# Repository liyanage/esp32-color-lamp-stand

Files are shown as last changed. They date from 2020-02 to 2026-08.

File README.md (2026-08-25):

# Color Lamp Stand — User Guide

This illuminated stand connects to Wi-Fi and uses its 32 LEDs to show whether
a stock selected in the firmware is up or down: green for up, red for down, and
white when no current value is available. The stock cannot currently be changed
through the Wi-Fi setup page.

This is the default behavior, but you could modify the software to do something
completely different or custom with the LEDs and the Internet connection.

## Hardware

You need:

- A USB-C power source that can provide at least 1.5 A. A USB-C wall charger is
  ideal; a computer USB-C port also works.
- A USB-C cable for power.

Feed the cable through the base and tie a loose knot inside for strain relief,
as shown below. Do not pull the knot tight enough to damage the cable.

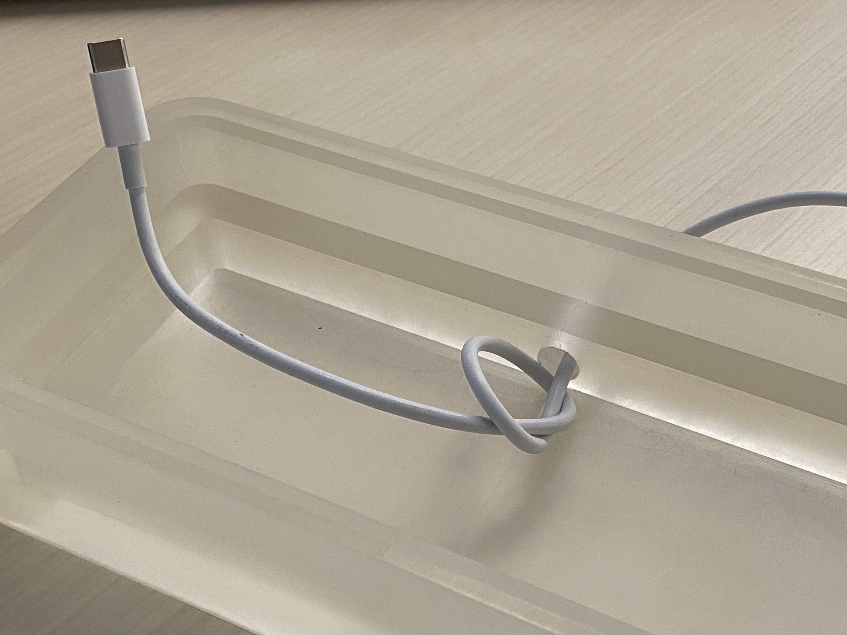
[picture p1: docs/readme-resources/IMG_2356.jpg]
Knot in USB-C cable for strain relief


Connect the USB-C plug to the socket on the circuit board.

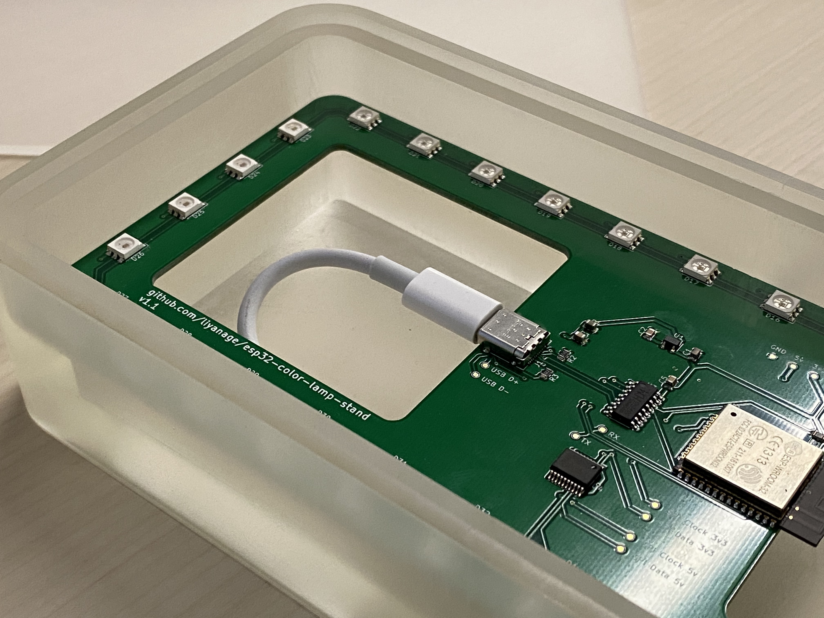
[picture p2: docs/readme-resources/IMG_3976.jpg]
USB-C cable plugged into the circuit board


Fit the translucent cover, then place the object you want to illuminate on top.

## Wi-Fi configuration

On first use, the stand pulses amber and creates a temporary Wi-Fi network named
`ColorLamp-Setup-XXXX`, where the last four characters are unique to your stand.

1. On a phone, tablet, or computer, open Wi-Fi settings and join that network.
   It intentionally has no password and may be described by your device as
   having no internet.
2. The setup page should open automatically. If it does not, open
   [http://192.168.4.1](http://192.168.4.1) in a web browser.
3. Select your home Wi-Fi network, enter its password, and choose **Connect**.
4. The stand pulses blue while it tests the connection. Green means setup
   succeeded and the stand will restart. Red means it could not connect; check
   the network and password, then try again.

Your Wi-Fi password is stored only on the stand.

### Changing the Wi-Fi network

With the stand fully started, hold the **BOOT** button on the circuit board for
five seconds. The LEDs turn red, the saved Wi-Fi details are erased, and the
stand restarts in setup mode.

Do not hold **BOOT** while plugging in power or pressing **RESET**. That button
also activates the ESP32's programming mode during startup.

## What the lights during startup mean

### Power check

Immediately after power-on, a short sweep reports how much current the connected
USB-C source advertises. The stand uses this information to limit LED brightness.
The sweep fills, pauses for about a second, and fades away.

USB-C power capability light patterns

- **8 amber LEDs — USB default:** The stand uses a conservative, low-brightness
  limit. For better illumination, try a USB-C charger rated for at least 1.5 A.
- **16 cyan LEDs — 1.5 A:** Normal operation with good available brightness.
- **32 green LEDs — 3 A:** The source advertises the highest supported current.
- **Two red flashes, then 8 amber LEDs:** The stand could not read the source
  capability and safely selected the conservative limit.

This is the capability advertised by the power source, not a measurement of how
much current the stand is presently consuming.

### Wi-Fi and setup

After the power check, the entire perimeter shows the Wi-Fi state.

Wi-Fi setup and connection light patterns

- **Solid blue:** Connecting to the saved Wi-Fi network.
- **Pulsing amber:** Waiting for you to join `ColorLamp-Setup-XXXX` and complete
  setup.
- **Pulsing blue:** Testing the Wi-Fi name and password you entered.
- **Solid green:** Connected successfully. After initial setup, the stand soon
  restarts automatically.
- **Solid red:** The attempted Wi-Fi connection failed.
- **Bright red after holding BOOT:** Saved Wi-Fi details are being erased.

## Troubleshooting

- **The setup page did not open:** Stay connected to `ColorLamp-Setup-XXXX` and
  open [http://192.168.4.1](http://192.168.4.1) manually. Temporarily disabling
  cellular data or a VPN can help if the phone leaves the setup network.
- **The stand keeps returning to amber setup mode:** Re-enter the Wi-Fi password
  and make sure the selected network is available where the stand will be used.
- **The light is unusually dim:** Check the power-on sweep. Eight amber LEDs mean
  the power source advertised only the default USB current; try another USB-C
  charger and cable.
- **You need to start over:** Let the stand finish booting, then hold **BOOT** for
  five seconds.

## Want to modify it?

The hardware and especially firmware are open for experimentation. See the
[modification guide](MODIFYING.md) for the source layout, fixed GPIO assignments,
KiCad design overview, and build workflow.

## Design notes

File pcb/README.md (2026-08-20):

# PCB development

The KiCad project files and the project-local symbol library are the hardware
sources. Edit the schematic in KiCad, update the PCB with `F8`, and route or
refill zones in the PCB Editor.

KiCad 10 and Python 3 are required. On macOS the exporter finds KiCad in
`/Applications/KiCad`; elsewhere, put `kicad-cli` on `PATH` or set
`KICAD_CLI`.

From this directory:

```sh
make check
make manufacturing
```

`make check` runs schematic ERC and PCB DRC, including schematic/PCB parity.
Error-level violations block the command. Review warnings in KiCad before export.

`make manufacturing` performs the checks and writes these upload-ready files
to `manufacturing/jlcpcb/`:

- `esp32-color-lamp-stand-gerbers.zip`
- `jlcpcb_bom.csv`
- `jlcpcb_cpl.csv`
- top and bottom preview images

The exporter omits test points, requires an LCSC number for every assembled
part, and verifies that BOM and CPL designators match. Review the previews and
run JLCPCB's online DFM analysis before ordering.

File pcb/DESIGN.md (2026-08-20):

# Version 2 hardware design

Version 2 replaces the original hand-assembled controller with a board intended
for complete JLCPCB assembly. Component selections and their LCSC identifiers
are stored in the schematic and exported into the manufacturing BOM.

## Controller and USB

The controller is an ESP32-S3-WROOM-1-N8R8 module. Its native USB interface is
connected to the USB-C receptacle through U2, a USBLC6-2SC6 USB ESD-protection
device. This removes the separate USB-to-serial IC used by the older design.

The module antenna intentionally extends beyond the PCB edge. Keep copper,
components, and enclosure material away from its antenna region; do not pull
the module inward merely to fit its body within the outline.

U3, an AP2112K-3.3 regulator, generates the 3.3 V rail from USB 5 V. The ESP32
module does not contain a regulator that accepts USB 5 V directly.

Each USB-C CC pin has the required 5.1 kOhm sink resistor. R9-R12 divide the CC1
and CC2 voltages for ESP32 ADC inputs. These readings indicate whether the
source advertises default current, 1.5 A, or 3 A; they do not measure the
board's actual current consumption. C42 and C43 provide local ADC filtering.

## LED power and data

The addressable LEDs operate from `LED_5V`. U5, a TPS22975 load switch, connects
USB `+5V` to `LED_5V` with controlled rise time. C40 programs its rise time,
C41 is its local input bypass capacitor, and C6 supplies bulk capacitance on the
switched LED rail.

U4, a 74AHCT1G125 powered from `LED_5V`, buffers and level-shifts the ESP32's
3.3 V LED data output. R7 is the series resistor between the buffer and the LED
chain. R8 holds the ESP32-side data signal low during reset or startup.

Each LED has a local 100 nF bypass capacitor. The firmware should still limit
brightness and total LED current to what the connected USB-C source advertises.

## Layout and assembly

The PCB is a two-layer design with filled GND zones on F.Cu and B.Cu and GND
stitching vias. The large routed openings and the external outline are part of
the mechanical design. The USB-C connector and ESP32 antenna placements are
edge-dependent and intentional.

All fitted components are on the top side. TP1-TP5 are bare test pads and are
excluded from the JLCPCB BOM and CPL. The project-local symbol library contains
the TPS22975 symbol required to open the schematic without external libraries.

Generate release files with:

```sh
make check
make manufacturing
```

The upload-ready outputs are written to `manufacturing/jlcpcb/`. The v2.0.0
release design is recorded by Git tag `v2.0.0`.

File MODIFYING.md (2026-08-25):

# Modifying the Color Lamp Stand

This document is for people who want to change the firmware or hardware. The
main [README](README.md) is the regular user guide.

## Software

The firmware is a small ESP-IDF 6 application for the
ESP32-S3-WROOM-1-N8R8. At a high level:

- `main/main.c` starts the hardware, configures Espressif's RMT/DMA-backed
  LED-strip driver, displays the USB power indication, reacts to Wi-Fi state
  changes, retrieves the stock value, and drives the LED effect.
- `main/wifi_manager.c` owns saved credentials, normal Wi-Fi connection, the
  temporary setup access point, captive web portal, and BOOT-button reset.
- `main/provisioning.html` is the setup page embedded in the firmware image.
- `main/usb_source.c` reads the USB-C CC voltage dividers and selects a safe LED
  brightness limit.
- `main/pixel.c` contains the color representation and interpolation helpers.

Activate ESP-IDF 6.0.2, then build and flash over the ESP32-S3's native USB
connection. The ESP-IDF component manager downloads the locked version of
Espressif's `led_strip` driver automatically:

```sh
. "$HOME/esp/esp-idf-v6.0.2/export.sh"
idf.py build
idf.py flash monitor
```

`main/idf_component.yml` declares the dependency and `dependencies.lock` pins
the resolved `led_strip` version to 3.0.3 for reproducible builds.

The hardware fixes only a few firmware-facing GPIO choices:

| Function | ESP32-S3 connection | Notes |
| --- | --- | --- |
| LED data | GPIO13 | Feeds the 74AHCT1G125 level shifter and then the first LED. |
| USB-C CC1 sense | GPIO4 / ADC1 channel 3 | Reads the divided CC1 voltage. |
| USB-C CC2 sense | GPIO5 / ADC1 channel 4 | Reads the divided CC2 voltage. |
| USB D− | GPIO19 | Native ESP32-S3 USB. |
| USB D+ | GPIO20 | Native ESP32-S3 USB. |
| BOOT button | GPIO0 | Held for five seconds after startup to erase saved Wi-Fi details. |

The current application happens to be a Wi-Fi-connected stock indicator, but
nothing requires you to preserve it. Feel free to ignore or delete the existing
firmware and turn the board into a completely new, custom 32-pixel ESP32-S3
project—the table above is the essential hardware contract.

## Hardware

The authoritative design is the KiCad project in `pcb/`. The images below are
published for convenient inspection; use the KiCad files when making changes.

Complete board schematic

*Complete schematic — select the image to open the full-resolution vector view.*

Top copper PCB layout

*Top copper, solder mask, silkscreen, holes, and board outline.*

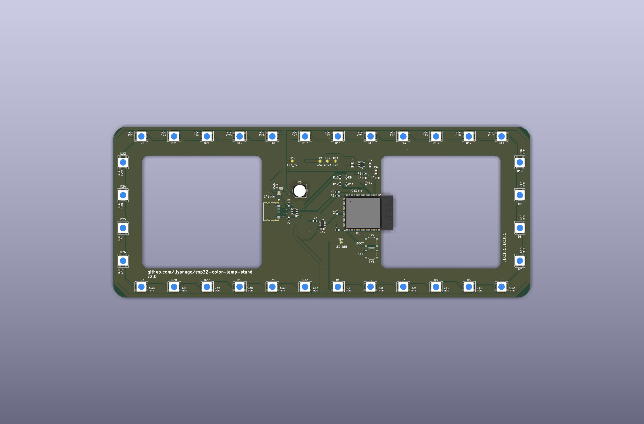
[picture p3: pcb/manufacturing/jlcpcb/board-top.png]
Top-side PCB assembly


*3D top-side assembly render.*

The main hardware blocks are:

- **ESP32-S3-WROOM-1-N8R8:** Wi-Fi controller with native USB.
- **32 addressable RGB LEDs:** A perimeter chain, each with a local 100 nF bypass
  capacitor.
- **AP2112K-3.3 regulator:** Converts USB 5 V to the ESP32's 3.3 V supply.
- **TPS22975 load switch:** Soft-starts and sequences the LED 5 V rail. Its
  enable input comes from the 3.3 V rail, so the ESP32-side supply starts before
  the LEDs; C40 then sets a controlled output-voltage ramp. This prevents the
  220 µF bulk capacitor, the LEDs' local bypass capacitors, and the LED
  electronics from all charging abruptly when USB-C power is connected,
  reducing inrush current and the resulting dip on the USB 5 V rail. Its low
  on-resistance carries the normal LED current efficiently, and it includes
  thermal shutdown, but it does not regulate the voltage or provide current
  limiting. The 220 µF capacitor supplies short LED load transients after
  startup.
- **74AHCT1G125 buffer:** Converts the ESP32's 3.3 V LED data signal to a robust
  5 V logic level.
- **USBLC6-2SC6 protection:** Protects the native USB data pair against static
  discharge.
- **USB-C CC resistors and ADC dividers:** Present the board as a USB-C sink and
  let firmware distinguish default, 1.5 A, and 3 A source advertisements.
- **RESET and BOOT buttons plus test pads:** Support recovery, programming, and
  diagnosis. Test pads are intentionally excluded from assembly.

The PCB has two copper layers with ground zones on both sides.

KiCad 10 and Python 3 are used for the hardware workflow:

```sh
make -C pcb check
make -C pcb manufacturing
```

The first command runs ERC, DRC, connectivity, and schematic/PCB parity checks.
The second also regenerates the JLCPCB Gerber ZIP, BOM, placement file, and board
renders in `pcb/manufacturing/jlcpcb/`. Component LCSC numbers live in the
schematic so assembly exports remain reproducible.

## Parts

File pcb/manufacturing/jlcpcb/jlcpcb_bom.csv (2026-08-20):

Comment | Designator | Footprint | LCSC Part # | Quantity
4.7uF | C1 | Capacitor_SMD:C_0805_2012Metric | C1779 | 1
10uF | C2,C4 | Capacitor_SMD:C_0805_2012Metric | C15850 | 2
100nF | C3,C7,C8,C9,C10,C11,C12,C13,C14,C15,C16,C17,C18,C19,C20,C21,C22,C23,C24,C25,C26,C27,C28,C29,C30,C31,C32,C33,C34,C35,C36,C37,C38,C39,C42,C43 | Capacitor_SMD:C_0603_1608Metric | C14663 | 36
1uF | C5,C41 | Capacitor_SMD:C_0603_1608Metric | C15849 | 2
220uF | C6 | Capacitor_SMD:C_Elec_6.3x5.8 | C3345 | 1
10nF | C40 | Capacitor_SMD:C_0603_1608Metric | C57112 | 1
XL-5050RGBC-2812B-S | D1,D2,D3,D4,D5,D6,D7,D8,D9,D10,D11,D12,D13,D14,D15,D16,D17,D18,D19,D20,D21,D22,D23,D24,D25,D26,D27,D28,D29,D30,D31,D32 | LED_SMD:LED_WS2812B_PLCC4_5.0x5.0mm_P3.2mm | C22461793 | 32
TYPE-C-31-M-12 | J1 | Connector_USB:USB_C_Receptacle_HRO_TYPE-C-31-M-12 | C165948 | 1
5.1k | R1,R2 | Resistor_SMD:R_0603_1608Metric | C23186 | 2
22R | R3,R4 | Resistor_SMD:R_0603_1608Metric | C23345 | 2
10k | R5,R6,R8 | Resistor_SMD:R_0603_1608Metric | C25804 | 3
470R | R7 | Resistor_SMD:R_0603_1608Metric | C23179 | 1
100k | R9,R10,R11,R12 | Resistor_SMD:R_0603_1608Metric | C25803 | 4
RESET | SW1 | Button_Switch_SMD:SW_Push_1P1T_XKB_TS-1187A | C318884 | 1
BOOT | SW2 | Button_Switch_SMD:SW_Push_1P1T_XKB_TS-1187A | C318884 | 1
ESP32-S3-WROOM-1-N8R8 | U1 | RF_Module:ESP32-S3-WROOM-1 | C2913201 | 1
USBLC6-2SC6 | U2 | Package_TO_SOT_SMD:SOT-23-6 | C7519 | 1
AP2112K-3.3TRG1 | U3 | Package_TO_SOT_SMD:SOT-23-5 | C23380830 | 1
74AHCT1G125W5-7 | U4 | Package_TO_SOT_SMD:SOT-23-5 | C842287 | 1
TPS22975DSGR | U5 | Package_SON:Texas_DSG0008A_WSON-8-1EP_2x2mm_P0.5mm_EP0.9x1.6mm | C524777 | 1

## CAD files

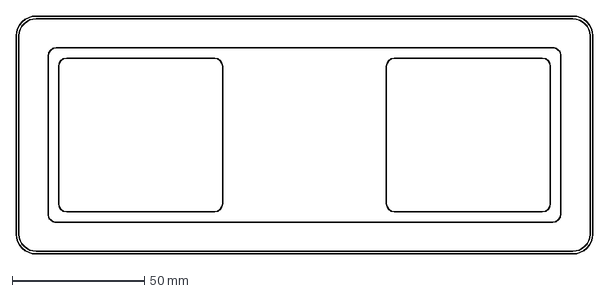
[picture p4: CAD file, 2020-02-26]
pcb/pcb shape.dxf
218.0 x 90.0 mm

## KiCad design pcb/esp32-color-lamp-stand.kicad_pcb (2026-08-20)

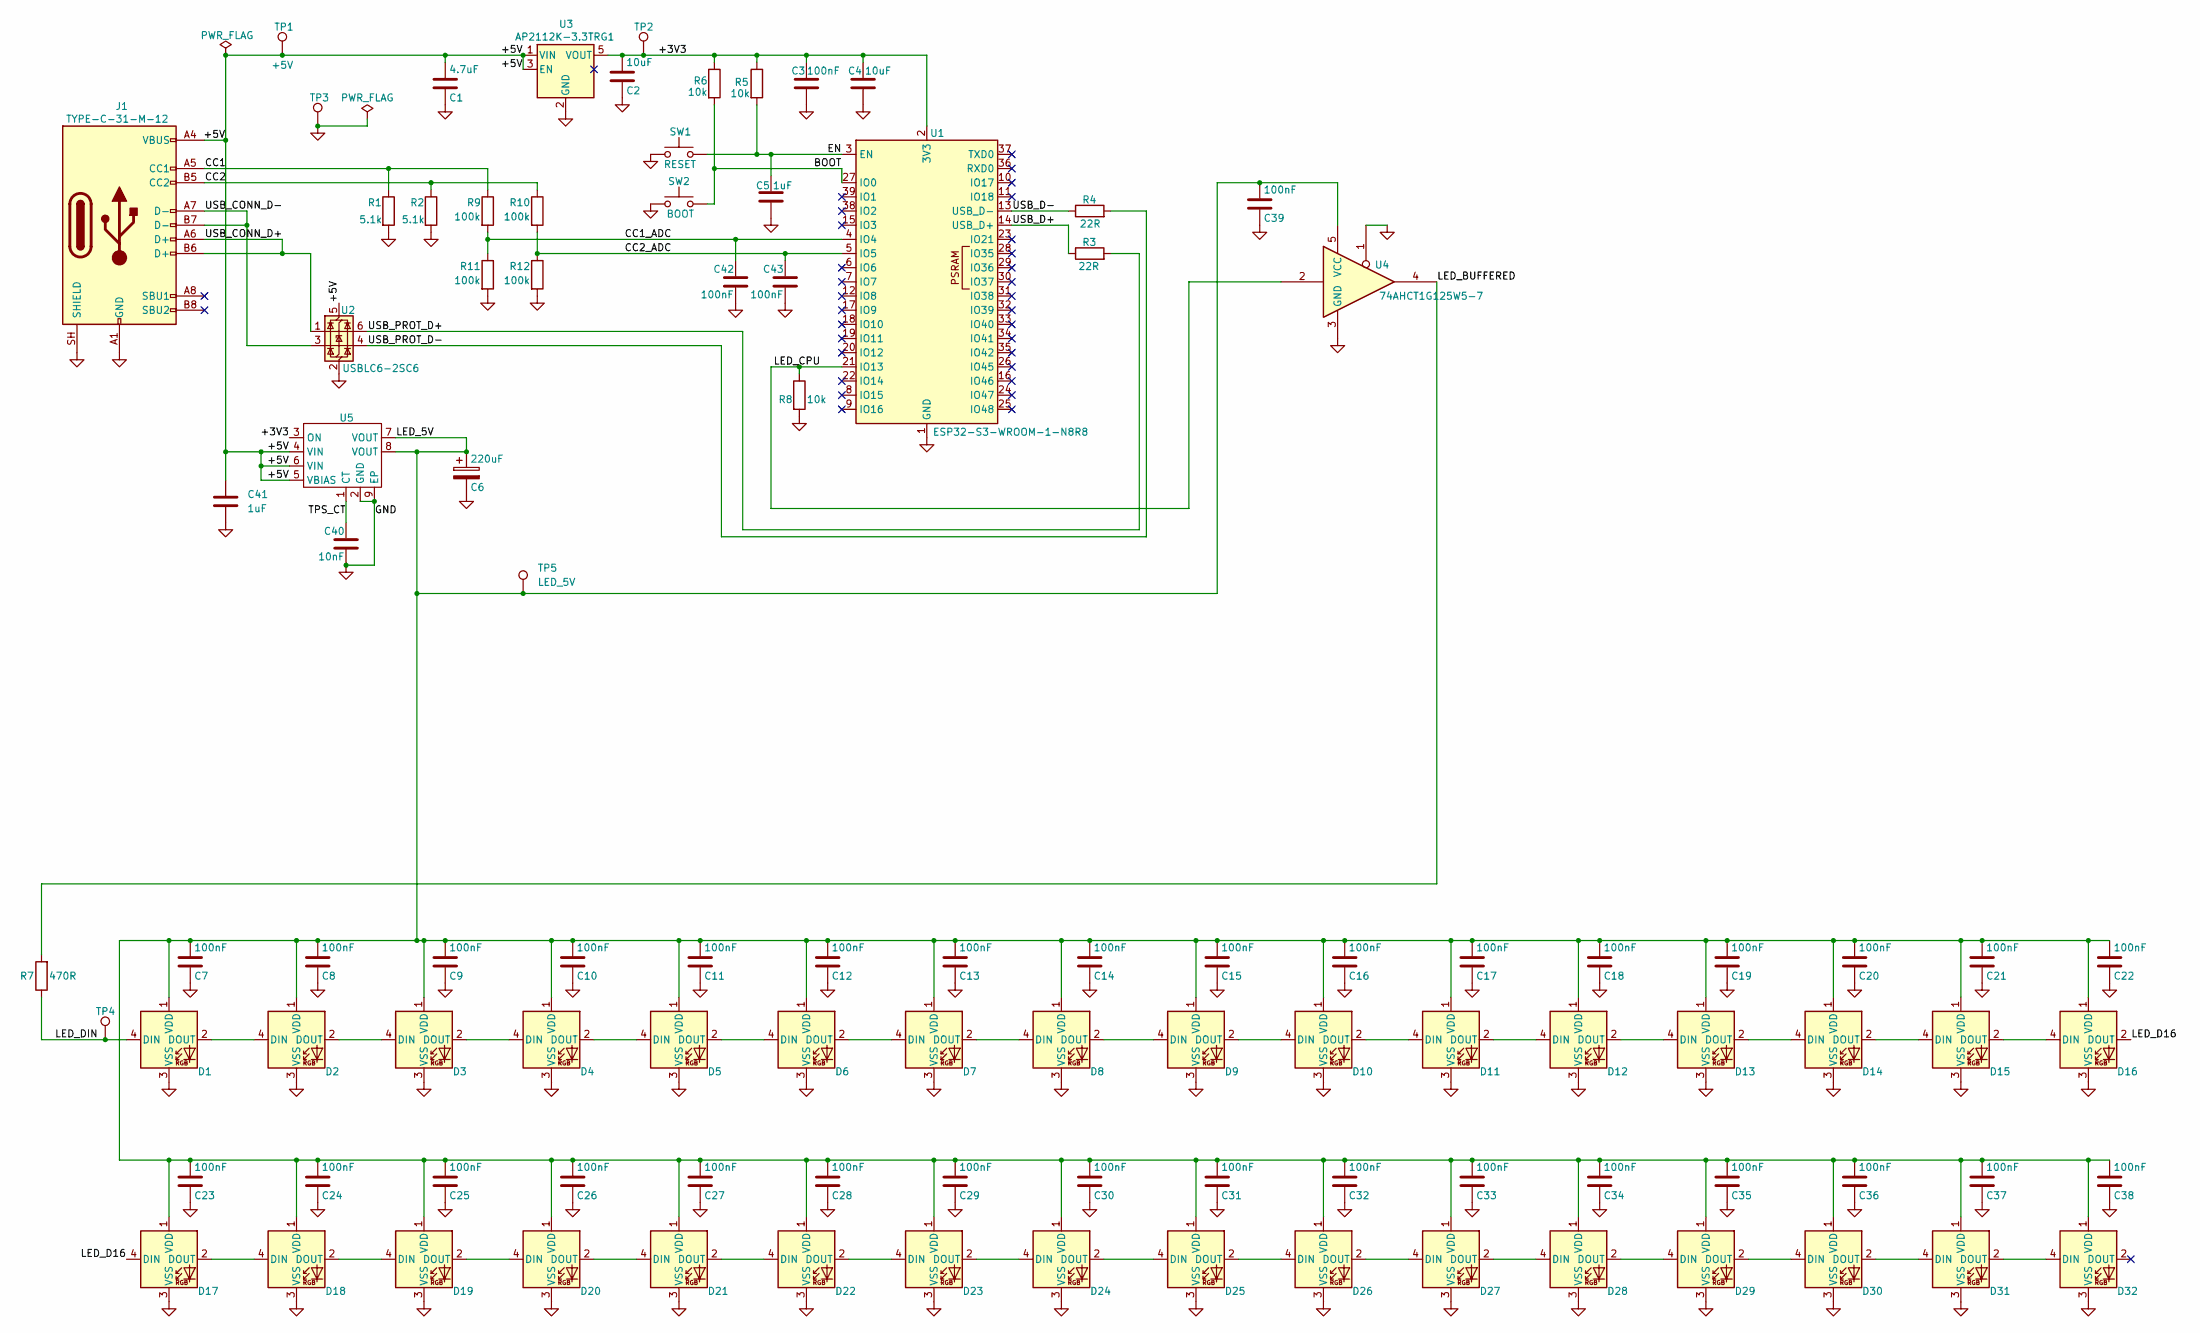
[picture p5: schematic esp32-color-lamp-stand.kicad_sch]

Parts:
C1: 4.7uF; C_0805_2012Metric; Manufacturer Part Number 4.7uF; LCSC C1779
C2, C4: 10uF; C_0805_2012Metric; Manufacturer Part Number 10uF; LCSC C15850
C3, C7, C8, C9, C10, C11, C12, C13, C14, C15, C16, C17, C18, C19, C20, C21, C22, C23, C24, C25, C26, C27, C28, C29, C30, C31, C32, C33, C34, C35, C36, C37, C38, C39: 100nF; C_0603_1608Metric; Manufacturer Part Number 100nF; LCSC C14663
C5: 1uF; C_0603_1608Metric; Manufacturer Part Number 1uF; LCSC C15849
C6: 220uF; C_Elec_6.3x5.8; Manufacturer Part Number RVT1A221M0605; LCSC C3345
C40: 10nF; C_0603_1608Metric; Manufacturer Part Number 10nF; LCSC C57112
C41: 1uF; C_0603_1608Metric; LCSC C15849
C42, C43: 100nF; C_0603_1608Metric; LCSC C14663
D1, D2, D3, D4, D5, D6, D7, D8, D9, D10, D11, D12, D13, D14, D15, D16, D17, D18, D19, D20, D21, D22, D23, D24, D25, D26, D27, D28, D29, D30, D31, D32: XL-5050RGBC-2812B-S; LED_WS2812B_PLCC4_5.0x5.0mm_P3.2mm; Manufacturer Part Number XL-5050RGBC-2812B-S; LCSC C22461793
J1: TYPE-C-31-M-12; USB_C_Receptacle_HRO_TYPE-C-31-M-12; Manufacturer Part Number TYPE-C-31-M-12; LCSC C165948
R1, R2: 5.1k; R_0603_1608Metric; Manufacturer Part Number 5.1k; LCSC C23186
R3, R4: 22R; R_0603_1608Metric; Manufacturer Part Number 22R; LCSC C23345
R5, R6, R8: 10k; R_0603_1608Metric; Manufacturer Part Number 10k; LCSC C25804
R7: 470R; R_0603_1608Metric; Manufacturer Part Number 470R; LCSC C23179
R9, R10, R11, R12: 100k; R_0603_1608Metric; Manufacturer Part Number 100k; LCSC C25803
SW1: RESET; SW_Push_1P1T_XKB_TS-1187A; Manufacturer Part Number TS-1187A-B-A-B; LCSC C318884
SW2: BOOT; SW_Push_1P1T_XKB_TS-1187A; Manufacturer Part Number TS-1187A-B-A-B; LCSC C318884
TP1: +5V; TestPoint_Pad_D1.0mm; Manufacturer Part Number DNP; LCSC DNP
TP2: +3V3; TestPoint_Pad_D1.0mm; Manufacturer Part Number DNP; LCSC DNP
TP3: GND; TestPoint_Pad_D1.0mm; Manufacturer Part Number DNP; LCSC DNP
TP4: LED_DIN; TestPoint_Pad_D1.0mm; Manufacturer Part Number DNP; LCSC DNP
TP5: LED_5V; TestPoint_Pad_D1.0mm
U1: ESP32-S3-WROOM-1-N8R8; ESP32-S3-WROOM-1; Manufacturer Part Number ESP32-S3-WROOM-1-N8R8; LCSC C2913201
U2: USBLC6-2SC6; SOT-23-6; Manufacturer Part Number USBLC6-2SC6; LCSC C7519
U3: AP2112K-3.3TRG1; SOT-23-5; Manufacturer Part Number AP2112K-3.3TRG1; LCSC C23380830
U4: 74AHCT1G125W5-7; SOT-23-5; Manufacturer Part Number 74AHCT1G125W5-7; LCSC C842287
U5: TPS22975DSGR; Texas_DSG0008A_WSON-8-1EP_2x2mm_P0.5mm_EP0.9x1.6mm; Manufacturer Part Number TPS22975DSGR; LCSC C524777

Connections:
/+3V3: C2.1, C3.1, C4.1, R5.1, R6.1, TP2.1 (1_1), U1.2 (3V3), U3.5 (VOUT), U5.3 (ON)
/+5V: C1.1, C41.1, J1.A4 (VBUS), J1.A9 (VBUS), J1.B4 (VBUS), J1.B9 (VBUS), TP1.1 (1_1), U2.5 (VBUS), U3.1 (VIN), U3.3 (EN), U5.4 (VIN), U5.5 (VBIAS), U5.6 (VIN)
/BOOT: R6.2, SW2.2, U1.27 (IO0)
/CC1: J1.A5 (CC1), R1.1, R9.1
/CC1_ADC: C42.1, R9.2, R11.1, U1.4 (IO4)
/CC2: J1.B5 (CC2), R2.1, R10.1
/CC2_ADC: C43.1, R10.2, R12.1, U1.5 (IO5)
/EN: C5.1, R5.2, SW1.2, U1.3 (EN)
/LED_5V: C6.1, C7.1, C8.1, C9.1, C10.1, C11.1, C12.1, C13.1, C14.1, C15.1, C16.1, C17.1, C18.1, C19.1, C20.1, C21.1, C22.1, C23.1, C24.1, C25.1, C26.1, C27.1, C28.1, C29.1, C30.1, C31.1, C32.1, C33.1, C34.1, C35.1, C36.1, C37.1, C38.1, C39.1, D1.1 (VDD), D2.1 (VDD), D3.1 (VDD), D4.1 (VDD), D5.1 (VDD), D6.1 (VDD), D7.1 (VDD), D8.1 (VDD), D9.1 (VDD), D10.1 (VDD), D11.1 (VDD), D12.1 (VDD), D13.1 (VDD), D14.1 (VDD), D15.1 (VDD), D16.1 (VDD), D17.1 (VDD), D18.1 (VDD), D19.1 (VDD), D20.1 (VDD), D21.1 (VDD), D22.1 (VDD), D23.1 (VDD), D24.1 (VDD), D25.1 (VDD), D26.1 (VDD), D27.1 (VDD), D28.1 (VDD), D29.1 (VDD), D30.1 (VDD), D31.1 (VDD), D32.1 (VDD), TP5.1 (1_1), U4.5 (VCC), U5.7 (VOUT), U5.8 (VOUT)
/LED_BUFFERED: R7.2, U4.4
/LED_CPU: R8.1, U1.21 (IO13), U4.2
/LED_D16: D16.2 (DOUT), D17.4 (DIN)
/LED_DIN: D1.4 (DIN), R7.1, TP4.1 (1_1)
/TPS_CT: C40.1, U5.1 (CT)
/USB_CONN_D+: J1.A6 (D+), J1.B6 (D+), U2.1 (I/O1)
/USB_CONN_D-: J1.A7 (D-), J1.B7 (D-), U2.3 (I/O2)
/USB_D+: R3.1, U1.14 (USB_D+)
/USB_D-: R4.1, U1.13 (USB_D-)
/USB_PROT_D+: R3.2, U2.6 (I/O1)
/USB_PROT_D-: R4.2, U2.4 (I/O2)
GND: C1.2, C2.2, C3.2, C4.2, C5.2, C6.2, C7.2, C8.2, C9.2, C10.2, C11.2, C12.2, C13.2, C14.2, C15.2, C16.2, C17.2, C18.2, C19.2, C20.2, C21.2, C22.2, C23.2, C24.2, C25.2, C26.2, C27.2, C28.2, C29.2, C30.2, C31.2, C32.2, C33.2, C34.2, C35.2, C36.2, C37.2, C38.2, C39.2, C40.2, C41.2, C42.2, C43.2, D1.3 (VSS), D2.3 (VSS), D3.3 (VSS), D4.3 (VSS), D5.3 (VSS), D6.3 (VSS), D7.3 (VSS), D8.3 (VSS), D9.3 (VSS), D10.3 (VSS), D11.3 (VSS), D12.3 (VSS), D13.3 (VSS), D14.3 (VSS), D15.3 (VSS), D16.3 (VSS), D17.3 (VSS), D18.3 (VSS), D19.3 (VSS), D20.3 (VSS), D21.3 (VSS), D22.3 (VSS), D23.3 (VSS), D24.3 (VSS), D25.3 (VSS), D26.3 (VSS), D27.3 (VSS), D28.3 (VSS), D29.3 (VSS), D30.3 (VSS), D31.3 (VSS), D32.3 (VSS), J1.A1 (GND), J1.A12 (GND), J1.B1 (GND), J1.B12 (GND), J1.SH (SHIELD), R1.2, R2.2, R8.2, R11.2, R12.2, SW1.1, SW2.1, TP3.1 (1_1), U1.1 (GND), U1.40 (GND), U1.41 (GND), U2.2 (GND), U3.2 (GND), U4.1, U4.3 (GND), U5.2 (GND), U5.9 (EP)
unnamed: D1.2 (DOUT), D2.4 (DIN)
unnamed: D2.2 (DOUT), D3.4 (DIN)
unnamed: D3.2 (DOUT), D4.4 (DIN)
unnamed: D4.2 (DOUT), D5.4 (DIN)
unnamed: D5.2 (DOUT), D6.4 (DIN)
unnamed: D6.2 (DOUT), D7.4 (DIN)
unnamed: D7.2 (DOUT), D8.4 (DIN)
unnamed: D8.2 (DOUT), D9.4 (DIN)
unnamed: D9.2 (DOUT), D10.4 (DIN)
unnamed: D10.2 (DOUT), D11.4 (DIN)
unnamed: D11.2 (DOUT), D12.4 (DIN)
unnamed: D12.2 (DOUT), D13.4 (DIN)
unnamed: D13.2 (DOUT), D14.4 (DIN)
unnamed: D14.2 (DOUT), D15.4 (DIN)
unnamed: D15.2 (DOUT), D16.4 (DIN)
unnamed: D17.2 (DOUT), D18.4 (DIN)
unnamed: D18.2 (DOUT), D19.4 (DIN)
unnamed: D19.2 (DOUT), D20.4 (DIN)
unnamed: D20.2 (DOUT), D21.4 (DIN)
unnamed: D21.2 (DOUT), D22.4 (DIN)
unnamed: D22.2 (DOUT), D23.4 (DIN)
unnamed: D23.2 (DOUT), D24.4 (DIN)
unnamed: D24.2 (DOUT), D25.4 (DIN)
unnamed: D25.2 (DOUT), D26.4 (DIN)
unnamed: D26.2 (DOUT), D27.4 (DIN)
unnamed: D27.2 (DOUT), D28.4 (DIN)
unnamed: D28.2 (DOUT), D29.4 (DIN)
unnamed: D29.2 (DOUT), D30.4 (DIN)
unnamed: D30.2 (DOUT), D31.4 (DIN)
unnamed: D31.2 (DOUT), D32.4 (DIN)

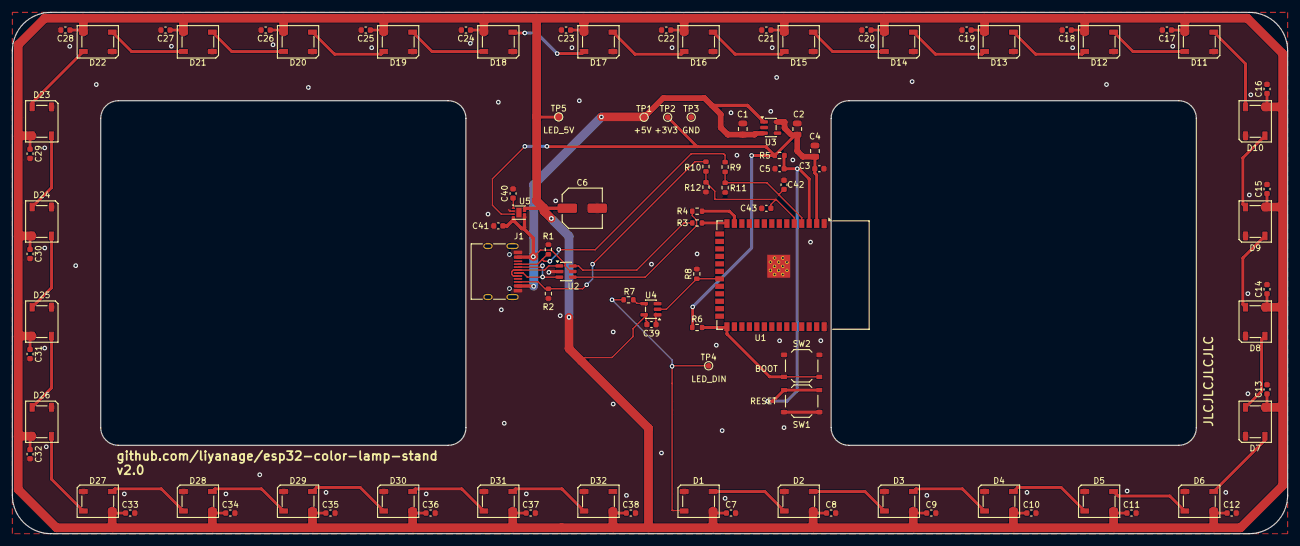
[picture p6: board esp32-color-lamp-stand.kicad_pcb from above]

Board: 2 copper layers, 216.5 x 88.5 mm, 100 parts (0 on the bottom side), 51 nets.

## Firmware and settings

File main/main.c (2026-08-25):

#include <stdio.h>
#include <string.h>
#include <stdbool.h>

#include "sdkconfig.h"
#include "freertos/FreeRTOS.h"
#include "freertos/semphr.h"
#include "freertos/task.h"
#include "esp_log.h"
#include "esp_mac.h"
#include "esp_system.h"
#include "esp_event.h"
#include "esp_wifi.h"
#include "esp_netif.h"
#include "esp_timer.h"
#include "esp_http_client.h"
#include "esp_crt_bundle.h"
#include "led_strip.h"
#include "pixel.h"
#include "usb_source.h"
#include "wifi_manager.h"

// Test mode uses a random number instead of performing an HTTP request
#define LED_TEST_MODE 0

#define LED_DATA_GPIO 13

#define LED_COUNT 32

#define ANIMATION_UPDATE_RATE_HZ 60
#define ANIMATION_DURATION_SECONDS 3.0

/* app state machine */
typedef enum application_state {
    application_state_start,
    application_state_offline,
    application_state_online,
} application_state;

#define ENUM_TO_STRING_CASE(x) case x: return #x
char *application_state_label_for_value(application_state state);
char *application_state_label_for_value(application_state state) {
    switch (state) {
        ENUM_TO_STRING_CASE(application_state_start);
        ENUM_TO_STRING_CASE(application_state_offline);
        ENUM_TO_STRING_CASE(application_state_online);
    }
    return NULL;
}

/* app state data */
typedef struct application_data {
    application_state state;
    esp_timer_handle_t periodic_timer;
    led_strip_handle_t led_strip;
    bool timer_is_armed;
    bool have_valid_value;
    double value;
    pixel_color_t current_pixel_color;
} application_data_t;

static application_data_t application_data;

typedef struct stock_data {
    bool have_valid_value;
    double value;
} stock_data_t;

/* prototypes */
static void periodic_timer_callback(void* arg);
static void initialize_led_strip(application_data_t *app_data);
static void start_timer(application_data_t *app_data);
static void stop_timer(application_data_t *app_data);
esp_err_t _http_event_handle_nasdaq(esp_http_client_event_t *evt);
static void update_led_strip(pixel_color_t pixel_color, led_strip_handle_t led_strip);
static void query_stock_data_and_update_led_strip(application_data_t *app_data);
static void wifi_status_changed(wifi_setup_status_t status);
static void show_usb_power_capability(usb_source_measurement_t measurement,
                                      led_strip_handle_t led_strip);
void application_transition_to_state(application_state *current_state, application_state new_state);
void get_stock_data_nasdaq(stock_data_t *stock_data);

static const char *LOG_TAG = "color-lamp-stand-app";
static uint8_t maximum_led_brightness = 3;
static SemaphoreHandle_t led_mutex;

void application_transition_to_state(application_state *current_state, application_state new_state) {
    ESP_LOGI(LOG_TAG, "*** Application state transition from %s to %s\n", application_state_label_for_value(*current_state), application_state_label_for_value(new_state));
    *current_state = new_state;
}


void wifi_event_handler(void *event_handler_arg, esp_event_base_t event_base, int32_t event_id, void *event_data) {
    ESP_LOGI(LOG_TAG, "Wifi event handler, event id %d, event data %p", event_id, event_data);
    application_data_t *app_data = event_handler_arg;

    if (event_id == WIFI_EVENT_STA_START) {
        ESP_LOGI(LOG_TAG, "WIFI_EVENT_STA_START");
    } else if (event_id == WIFI_EVENT_STA_CONNECTED) {
        ESP_LOGI(LOG_TAG, "WIFI_EVENT_STA_CONNECTED");
    } else if (event_id == WIFI_EVENT_STA_DISCONNECTED) {
        ESP_LOGI(LOG_TAG, "WIFI_EVENT_STA_DISCONNECTED");
        application_transition_to_state(&app_data->state, application_state_offline);
        stop_timer(app_data);
    }    
}

void ip_event_handler(void *event_handler_arg, esp_event_base_t event_base, int32_t event_id, void *event_data) {
    ESP_LOGI(LOG_TAG, "IP event handler, event id %d, event data %p", event_id, event_data);
    application_data_t *app_data = event_handler_arg;

    if (event_id == IP_EVENT_STA_GOT_IP) {
        ESP_LOGI(LOG_TAG, "IP_EVENT_STA_GOT_IP");

        application_transition_to_state(&app_data->state, application_state_online);
        // force an initial update
        query_stock_data_and_update_led_strip(app_data);
        start_timer(app_data);
    } else if (0) {

    }    

}


void app_main(void)
{
    ESP_LOGI(LOG_TAG, "Starting color lamp stand");

    usb_source_measurement_t usb_source = usb_source_measure();
    maximum_led_brightness = usb_source.maximum_led_brightness;

    initialize_led_strip(&application_data);
    update_led_strip(pixel_color_black, application_data.led_strip);
    show_usb_power_capability(usb_source, application_data.led_strip);

    const esp_timer_create_args_t periodic_timer_args = {
            .callback = &periodic_timer_callback,
            .arg = (void *) &application_data,
            .name = "periodic"
    };

    ESP_ERROR_CHECK(esp_timer_create(&periodic_timer_args, &application_data.periodic_timer));

    ESP_ERROR_CHECK(wifi_manager_initialize_and_connect(wifi_status_changed));
    ESP_ERROR_CHECK(esp_event_handler_register(WIFI_EVENT, ESP_EVENT_ANY_ID,
                                               wifi_event_handler, &application_data));
    ESP_ERROR_CHECK(esp_event_handler_register(IP_EVENT, IP_EVENT_STA_GOT_IP,
                                               ip_event_handler, &application_data));
    wifi_manager_start_reset_button_monitor(wifi_status_changed);

    application_transition_to_state(&application_data.state, application_state_online);
    query_stock_data_and_update_led_strip(&application_data);
    start_timer(&application_data);

}

static void wifi_status_changed(wifi_setup_status_t status)
{
    pixel_color_t color = pixel_color_black;
    switch (status) {
        case WIFI_SETUP_STATUS_CONNECTING:
            color = (pixel_color_t){.brightness = 6, .b = 0xff};
            break;
        case WIFI_SETUP_STATUS_PORTAL:
            color = (pixel_color_t){.brightness = 12, .r = 0xff, .g = 0x60};
            break;
        case WIFI_SETUP_STATUS_PORTAL_DIM:
            color = (pixel_color_t){.brightness = 3, .r = 0xff, .g = 0x60};
            break;
        case WIFI_SETUP_STATUS_TESTING:
            color = (pixel_color_t){.brightness = 12, .b = 0xff};
            break;
        case WIFI_SETUP_STATUS_TESTING_DIM:
            color = (pixel_color_t){.brightness = 3, .b = 0xff};
            break;
        case WIFI_SETUP_STATUS_FAILED:
            color = (pixel_color_t){.brightness = 8, .r = 0xff};
            break;
        case WIFI_SETUP_STATUS_CONNECTED:
            color = (pixel_color_t){.brightness = 8, .g = 0xff};
            break;
        case WIFI_SETUP_STATUS_RESETTING:
            color = (pixel_color_t){.brightness = 15, .r = 0xff};
            break;
    }
    update_led_strip(color, application_data.led_strip);
}

static void initialize_led_strip(application_data_t *app_data)
{
    led_strip_config_t strip_config = {
        .strip_gpio_num = LED_DATA_GPIO,
        .max_leds = LED_COUNT,
        .led_model = LED_MODEL_WS2812,
        .color_component_format = LED_STRIP_COLOR_COMPONENT_FMT_GRB,
        .flags.invert_out = false,
    };
    led_strip_rmt_config_t rmt_config = {
        .clk_src = RMT_CLK_SRC_DEFAULT,
        .resolution_hz = 10 * 1000 * 1000,
        .mem_block_symbols = 0,
        .flags.with_dma = true,
    };
    ESP_ERROR_CHECK(led_strip_new_rmt_device(&strip_config, &rmt_config,
                                             &app_data->led_strip));

    led_mutex = xSemaphoreCreateMutex();
    ESP_ERROR_CHECK(led_mutex == NULL ? ESP_ERR_NO_MEM : ESP_OK);
}

static void start_timer(application_data_t *app_data) {
    if (!app_data->timer_is_armed) {
        ESP_LOGI(LOG_TAG, "Starting timer");
#if LED_TEST_MODE
        ESP_ERROR_CHECK(esp_timer_start_periodic(app_data->periodic_timer, 5 * 1000000));
#else
        ESP_ERROR_CHECK(esp_timer_start_periodic(app_data->periodic_timer, 5 * 60 * 1000000));
#endif
        app_data->timer_is_armed = true;
    }
}

static void stop_timer(application_data_t *app_data) {
    if (app_data->timer_is_armed) {
        ESP_LOGI(LOG_TAG, "Stopping timer");
        ESP_ERROR_CHECK(esp_timer_stop(app_data->periodic_timer));
        app_data->timer_is_armed = false;
    }
}

static void periodic_timer_callback(void* arg)
{
    int64_t time_since_boot = esp_timer_get_time();
    ESP_LOGI(LOG_TAG, "Periodic timer called, time since boot: %lld us", time_since_boot);
    application_data_t *app_data = arg;
    query_stock_data_and_update_led_strip(app_data);
}

static void query_stock_data_and_update_led_strip(application_data_t *app_data) {
    ESP_LOGI(LOG_TAG, "Querying data");

    stock_data_t data;
    bzero(&data, sizeof(data));

#if LED_TEST_MODE
    data.have_valid_value = true;
    data.value = esp_random() % 2 ? -1.0 : 1.0;
#else
    get_stock_data_nasdaq(&data);
#endif

    pixel_color_t new_color = pixel_color_white;
    if (data.have_valid_value) {
        ESP_LOGI(LOG_TAG, "New value %f", data.value);
        new_color = data.value < 0 ? pixel_color_red : pixel_color_green;
    } else {
        ESP_LOGE(LOG_TAG, "Unable to get valid value");
    }

    if (pixel_color_equal(app_data->current_pixel_color, new_color)) {
        ESP_LOGI(LOG_TAG, "No value/color change, skipping LED update");
        return;
    }

    int update_steps = ANIMATION_DURATION_SECONDS * ANIMATION_UPDATE_RATE_HZ;
    double update_increment = 1.0 / update_steps;
    TickType_t update_step_delay_ticks = ((TickType_t)(ANIMATION_DURATION_SECONDS * 1000) / update_steps / portTICK_PERIOD_MS);
    for (double x = 0.0; x <= 1.0; x += update_increment) {
        // pixel_color_t step_color = interpolate_pixel_color(app_data->current_pixel_color, new_color, x);
        pixel_color_t step_color = interpolate_pixel_color3(app_data->current_pixel_color, pixel_color_black, new_color, x);
        update_led_strip(step_color, app_data->led_strip);
        vTaskDelay(update_step_delay_ticks);
    }

    app_data->current_pixel_color = new_color;

}

static uint8_t apply_brightness(uint8_t channel, uint8_t brightness)
{
    return ((uint16_t)channel * brightness + 15) / 31;
}

static void update_led_strip_pixels(const pixel_color_t pixels[LED_COUNT],
                                    led_strip_handle_t led_strip)
{
    xSemaphoreTake(led_mutex, portMAX_DELAY);

    for (int pixel = 0; pixel < LED_COUNT; ++pixel) {
        uint8_t brightness = pixels[pixel].brightness;
        if (brightness > maximum_led_brightness) {
            brightness = maximum_led_brightness;
        }
        uint8_t red = apply_brightness(pixels[pixel].r, brightness);
        uint8_t green = apply_brightness(pixels[pixel].g, brightness);
        uint8_t blue = apply_brightness(pixels[pixel].b, brightness);
        ESP_ERROR_CHECK(led_strip_set_pixel(led_strip, pixel, red, green, blue));
    }
    ESP_ERROR_CHECK(led_strip_refresh(led_strip));
    xSemaphoreGive(led_mutex);
}

static void update_led_strip(pixel_color_t pixel_color, led_strip_handle_t led_strip)
{
    pixel_color_t pixels[LED_COUNT];
    for (int pixel = 0; pixel < LED_COUNT; ++pixel) {
        pixels[pixel] = pixel_color;
    }
    update_led_strip_pixels(pixels, led_strip);
}

static void show_usb_power_capability(usb_source_measurement_t measurement,
                                      led_strip_handle_t led_strip)
{
    if (!measurement.measurement_valid) {
        pixel_color_t error = {.brightness = 10, .r = 0xff};
        for (int flash = 0; flash < 2; ++flash) {
            update_led_strip(error, led_strip);
            vTaskDelay(pdMS_TO_TICKS(180));
            update_led_strip(pixel_color_black, led_strip);
            vTaskDelay(pdMS_TO_TICKS(180));
        }
    }

    int illuminated_pixels;
    pixel_color_t gauge_color;
    switch (measurement.current) {
        case USB_SOURCE_CURRENT_3_A:
            illuminated_pixels = LED_COUNT;
            gauge_color = (pixel_color_t){.brightness = 10, .g = 0xff};
            break;
        case USB_SOURCE_CURRENT_1_5_A:
            illuminated_pixels = LED_COUNT / 2;
            gauge_color = (pixel_color_t){.brightness = 10, .g = 0x80, .b = 0xff};
            break;
        case USB_SOURCE_CURRENT_DEFAULT:
        default:
            illuminated_pixels = LED_COUNT / 4;
            gauge_color = (pixel_color_t){.brightness = 10, .r = 0xff, .g = 0x60};
            break;
    }

    pixel_color_t pixels[LED_COUNT] = {0};
    TickType_t sweep_delay = pdMS_TO_TICKS(500 / illuminated_pixels);
    for (int pixel = 0; pixel < illuminated_pixels; ++pixel) {
        pixels[pixel] = gauge_color;
        update_led_strip_pixels(pixels, led_strip);
        vTaskDelay(sweep_delay);
    }
    vTaskDelay(pdMS_TO_TICKS(1000));

    uint8_t starting_brightness = gauge_color.brightness;
    if (starting_brightness > maximum_led_brightness) {
        starting_brightness = maximum_led_brightness;
    }
    for (int brightness = starting_brightness; brightness >= 0; --brightness) {
        for (int pixel = 0; pixel < illuminated_pixels; ++pixel) {
            pixels[pixel].brightness = brightness;
        }
        update_led_strip_pixels(pixels, led_strip);
        vTaskDelay(pdMS_TO_TICKS(70));
    }
}

void get_stock_data_nasdaq(stock_data_t *stock_data) {
    esp_http_client_config_t config = {
        .url = "https://api.nasdaq.com/api/quote/AAPL/info?assetclass=stocks",
        .event_handler = _http_event_handle_nasdaq,
        .user_data = stock_data,
        .crt_bundle_attach = esp_crt_bundle_attach,
    };

    esp_http_client_handle_t client = esp_http_client_init(&config);
    esp_http_client_set_header(client, "Accept", "application/json, text/plain, */*");
    esp_http_client_set_header(client, "Origin", "https://www.nasdaq.com");
    esp_http_client_set_header(client, "Host", "api.nasdaq.com");
    esp_http_client_set_header(client, "Referer", "https://www.nasdaq.com/market-activity/stocks/aapl/real-time");
    esp_http_client_set_header(client, "Connection", "keep-alive");
    esp_http_client_set_header(client, "User-Agent", "Mozilla/5.0 (Macintosh; Intel Mac OS X 10_15) AppleWebKit/605.1.15 (KHTML, like Gecko) Version/13.0.2 Safari/605.1.15");
    esp_http_client_set_header(client, "Accept-Language", "en-us");

    esp_err_t err = esp_http_client_perform(client);
    if (err == ESP_OK) {
        ESP_LOGI(LOG_TAG, "Status = %d, content_length = %d", esp_http_client_get_status_code(client), esp_http_client_get_content_length(client));
    } else {
        ESP_LOGE(LOG_TAG, "Error performing HTTP request: %d", err);
    }
    esp_http_client_cleanup(client);
}

esp_err_t _http_event_handle_nasdaq(esp_http_client_event_t *evt) {
    stock_data_t *data = evt->user_data;

    switch(evt->event_id) {
        case HTTP_EVENT_HEADER_SENT:
        case HTTP_EVENT_ON_HEADER:
        case HTTP_EVENT_ON_HEADERS_COMPLETE:
        case HTTP_EVENT_ON_STATUS_CODE:
        case HTTP_EVENT_ON_CONNECTED:
        case HTTP_EVENT_ON_FINISH:
        case HTTP_EVENT_DISCONNECTED:
        case HTTP_EVENT_REDIRECT:
            break;

        case HTTP_EVENT_ERROR:
            ESP_LOGE(LOG_TAG, "HTTP_EVENT_ERROR");
            break;
        case HTTP_EVENT_ON_DATA:
            ESP_LOGI(LOG_TAG, "HTTP_EVENT_ON_DATA, len=%d chunked=%d", evt->data_len, esp_http_client_is_chunked_response(evt->client));
            ESP_LOGI(LOG_TAG, "%.*s\n", evt->data_len, (char*)evt->data);
            if (!(data->have_valid_value)) {
                char *match = memmem(evt->data, evt->data_len, "\"deltaIndicator\":", strlen("\"deltaIndicator\":"));
                if (match) {
                    bool up_match = memmem(evt->data, evt->data_len, "\"deltaIndicator\":\"up\"", strlen("\"deltaIndicator\":\"up\"")) != NULL;
                    bool down_match = memmem(evt->data, evt->data_len, "\"deltaIndicator\":\"down\"", strlen("\"deltaIndicator\":\"down\"")) != NULL;
                    if (up_match) {
                        ESP_LOGI(LOG_TAG, "Found 'up' indicator");
                        data->have_valid_value = true;
                        data->value = 1.0;
                    } else if (down_match) {
                        ESP_LOGI(LOG_TAG, "Found 'down' indicator");
                        data->have_valid_value = true;
                        data->value = -1.0;
                    } else {
                        ESP_LOGE(LOG_TAG, "Unable to find 'up' or 'down' value:");
                        ESP_LOGE(LOG_TAG, "%.*s", evt->data_len, (char*)evt->data);
                    }
                }                
            }
            break;
    }
    return ESP_OK;
}

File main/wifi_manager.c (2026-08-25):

#include "wifi_manager.h"

#include <stdbool.h>
#include <stdio.h>
#include <stdlib.h>
#include <string.h>

#include "driver/gpio.h"
#include "esp_check.h"
#include "esp_event.h"
#include "esp_http_server.h"
#include "esp_log.h"
#include "esp_mac.h"
#include "esp_netif.h"
#include "esp_system.h"
#include "esp_wifi.h"
#include "freertos/FreeRTOS.h"
#include "freertos/event_groups.h"
#include "freertos/task.h"
#include "lwip/inet.h"
#include "lwip/sockets.h"
#include "nvs.h"
#include "nvs_flash.h"

#define WIFI_NAMESPACE "storage"
#define WIFI_SSID_KEY "wifi_ssid"
#define WIFI_PASSWORD_KEY "wifi_password"
#define WIFI_SSID_SIZE 33
#define WIFI_PASSWORD_SIZE 65
#define WIFI_CONNECT_ATTEMPTS 3
#define WIFI_CONNECT_TIMEOUT_MS 45000
#define BOOT_BUTTON_GPIO GPIO_NUM_0
#define BOOT_BUTTON_HOLD_MS 5000
#define PORTAL_IP "192.168.4.1"

#define WIFI_CONNECTED_BIT BIT0
#define WIFI_FAILED_BIT BIT1

typedef enum {
    PORTAL_STATE_READY,
    PORTAL_STATE_TESTING,
    PORTAL_STATE_FAILED,
    PORTAL_STATE_CONNECTED,
} portal_state_t;

static const char *LOG_TAG = "wifi-manager";
static EventGroupHandle_t s_wifi_events;
static wifi_setup_status_callback_t s_status_callback;
static esp_netif_t *s_ap_netif;
static bool s_portal_active;
static bool s_initial_connecting;
static bool s_connect_requested;
static bool s_pending_credentials;
static unsigned int s_connect_attempts;
static portal_state_t s_portal_state = PORTAL_STATE_READY;
static char s_pending_ssid[WIFI_SSID_SIZE];
static char s_pending_password[WIFI_PASSWORD_SIZE];
static portMUX_TYPE s_state_lock = portMUX_INITIALIZER_UNLOCKED;

extern const unsigned char provisioning_html_start[] asm("_binary_provisioning_html_start");
extern const unsigned char provisioning_html_end[] asm("_binary_provisioning_html_end");

static void set_portal_state(portal_state_t state)
{
    portENTER_CRITICAL(&s_state_lock);
    s_portal_state = state;
    portEXIT_CRITICAL(&s_state_lock);
}

static portal_state_t get_portal_state(void)
{
    portENTER_CRITICAL(&s_state_lock);
    portal_state_t state = s_portal_state;
    portEXIT_CRITICAL(&s_state_lock);
    return state;
}

static esp_err_t initialize_nvs(void)
{
    esp_err_t err = nvs_flash_init();
    if (err == ESP_ERR_NVS_NO_FREE_PAGES || err == ESP_ERR_NVS_NEW_VERSION_FOUND) {
        ESP_RETURN_ON_ERROR(nvs_flash_erase(), LOG_TAG, "Unable to erase NVS");
        err = nvs_flash_init();
    }
    return err;
}

static bool load_credentials(char *ssid, size_t ssid_size, char *password, size_t password_size)
{
    nvs_handle_t handle;
    if (nvs_open(WIFI_NAMESPACE, NVS_READONLY, &handle) != ESP_OK) {
        return false;
    }

    size_t stored_ssid_size = ssid_size;
    size_t stored_password_size = password_size;
    esp_err_t ssid_result = nvs_get_str(handle, WIFI_SSID_KEY, ssid, &stored_ssid_size);
    esp_err_t password_result = nvs_get_str(handle, WIFI_PASSWORD_KEY, password, &stored_password_size);
    nvs_close(handle);
    return ssid_result == ESP_OK && password_result == ESP_OK && ssid[0] != '\0';
}

static esp_err_t save_pending_credentials(void)
{
    nvs_handle_t handle;
    ESP_RETURN_ON_ERROR(nvs_open(WIFI_NAMESPACE, NVS_READWRITE, &handle), LOG_TAG,
                        "Unable to open Wi-Fi settings");
    esp_err_t err = nvs_set_str(handle, WIFI_SSID_KEY, s_pending_ssid);
    if (err == ESP_OK) {
        err = nvs_set_str(handle, WIFI_PASSWORD_KEY, s_pending_password);
    }
    if (err == ESP_OK) {
        err = nvs_commit(handle);
    }
    nvs_close(handle);
    return err;
}

static void erase_credentials(void)
{
    nvs_handle_t handle;
    if (nvs_open(WIFI_NAMESPACE, NVS_READWRITE, &handle) != ESP_OK) {
        return;
    }
    nvs_erase_key(handle, WIFI_SSID_KEY);
    nvs_erase_key(handle, WIFI_PASSWORD_KEY);
    nvs_commit(handle);
    nvs_close(handle);
}

static void make_station_config(wifi_config_t *config, const char *ssid,
                                const char *password)
{
    memset(config, 0, sizeof(*config));
    size_t ssid_length = strnlen(ssid, WIFI_SSID_SIZE - 1);
    memcpy(config->sta.ssid, ssid, ssid_length);
    strlcpy((char *)config->sta.password, password, sizeof(config->sta.password));
    config->sta.threshold.authmode = WIFI_AUTH_OPEN;
}

static void restart_after_provisioning(void *unused)
{
    vTaskDelay(pdMS_TO_TICKS(3000));
    esp_restart();
}

static void wifi_event_handler(void *unused, esp_event_base_t event_base,
                               int32_t event_id, void *event_data)
{
    if (event_base == WIFI_EVENT && event_id == WIFI_EVENT_STA_START) {
        if (s_connect_requested) {
            esp_wifi_connect();
        }
        return;
    }

    if (event_base == WIFI_EVENT && event_id == WIFI_EVENT_STA_DISCONNECTED) {
        wifi_event_sta_disconnected_t *event = event_data;
        ESP_LOGW(LOG_TAG, "Wi-Fi disconnected, reason %d", event->reason);

        if (s_portal_active) {
            if (s_pending_credentials) {
                s_pending_credentials = false;
                set_portal_state(PORTAL_STATE_FAILED);
            }
            return;
        }

        if (s_initial_connecting) {
            ++s_connect_attempts;
            if (s_connect_attempts >= WIFI_CONNECT_ATTEMPTS) {
                xEventGroupSetBits(s_wifi_events, WIFI_FAILED_BIT);
                return;
            }
        }
        esp_wifi_connect();
        return;
    }

    if (event_base == IP_EVENT && event_id == IP_EVENT_STA_GOT_IP) {
        xEventGroupSetBits(s_wifi_events, WIFI_CONNECTED_BIT);
        s_initial_connecting = false;

        if (s_portal_active && s_pending_credentials) {
            if (save_pending_credentials() == ESP_OK) {
                s_pending_credentials = false;
                set_portal_state(PORTAL_STATE_CONNECTED);
                xTaskCreate(restart_after_provisioning, "wifi-restart", 2048, NULL, 5, NULL);
            } else {
                s_pending_credentials = false;
                set_portal_state(PORTAL_STATE_FAILED);
            }
        }
    }
}

static void url_decode(char *value)
{
    char *source = value;
    char *destination = value;
    while (*source != '\0') {
        if (*source == '+') {
            *destination++ = ' ';
            ++source;
        } else if (*source == '%' && source[1] != '\0' && source[2] != '\0') {
            char encoded[3] = {source[1], source[2], '\0'};
            *destination++ = (char)strtoul(encoded, NULL, 16);
            source += 3;
        } else {
            *destination++ = *source++;
        }
    }
    *destination = '\0';
}

static esp_err_t portal_page_handler(httpd_req_t *request)
{
    httpd_resp_set_type(request, "text/html");
    httpd_resp_set_hdr(request, "Cache-Control", "no-store");
    size_t page_size = provisioning_html_end - provisioning_html_start;
    return httpd_resp_send(request, (const char *)provisioning_html_start, page_size);
}
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

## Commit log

2020-02-26 Add KiCad PCB files
    [esp32-color-lamp-stand-B_Cu.gbr, esp32-color-lamp-stand-B_Mask.gbr, esp32-color-lamp-stand-B_Paste.gbr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]
2022-05-12 Update to ESP-IDF 4.4.1, fix broken HTTP request configuration
    [main.c]
2026-08-17 Migrate PCB files to Kicad 10, format conversion only checkpoint commit
    [esp32-color-lamp-stand.kicad_pcb, esp32-color-lamp-stand.kicad_sch, esp32-color-lamp-stand.sch]
2026-08-17 Complete ESP32-S3 PCB redesign and routing
    [esp32-color-lamp-stand.kicad_pcb, esp32-color-lamp-stand.kicad_sch, jlcpcb_bom.csv]
2026-08-20 Finalize ESP32-S3 PCB and manufacturing workflow
    [esp32-color-lamp-stand.kicad_pcb, esp32-color-lamp-stand.kicad_sch, jlcpcb_bom.csv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]
2026-08-20 Document PCB design and maintenance workflow
2026-08-20 Migrate firmware to ESP-IDF 6 and ESP32-S3
    [configuration_menu.h]
2026-08-25 Add captive Wi-Fi provisioning
    [configuration_menu.h]
2026-08-25 Show USB power capability at boot
2026-08-25 Drive LEDs with ESP32-S3 RMT
